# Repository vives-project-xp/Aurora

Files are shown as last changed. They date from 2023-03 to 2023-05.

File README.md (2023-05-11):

# Aurora

Our inspiration for this project is the northern lights in Norway. This is what we want to recreate using ledstrips <br />
We Also will try to develop a person detection system with sensors

Aurora

## Table of contents

- [Short discription](#short-discription)
- [Required](#required)
  - [Hardware](#hardware)
  - [Software](#software)
- [Installation](#installation)
- [Configuration](#configuration)
- [Troubleshooting](#troubleshooting)
- [FAQ](#faq)
- [Maintainers](#maintainers)
- [project photos](#mood-images)

## Short Discription

The project for the ARGB led strip and motion sensors. </br>
This is an interactive LED strip that tracks people and also can display random effects

## Required

These are the required software and hardware

### Software

- Wled
- Arduino
- HTML
- Python
- Javascript
- Docker

### Hardware

- ESP32
- TM1814 led strip
- kabel goot
- 2,5 carre kabels
- breadboard
- Voeding
- ultrasone sensor
- 3d printed brackets
- 3d printed joints

> You can find extra information to buy the right components [here](./HARDWARE.md).

## Installation

> You can find all the information to install this project [here](./INSTALLATION.md).

## Configuration

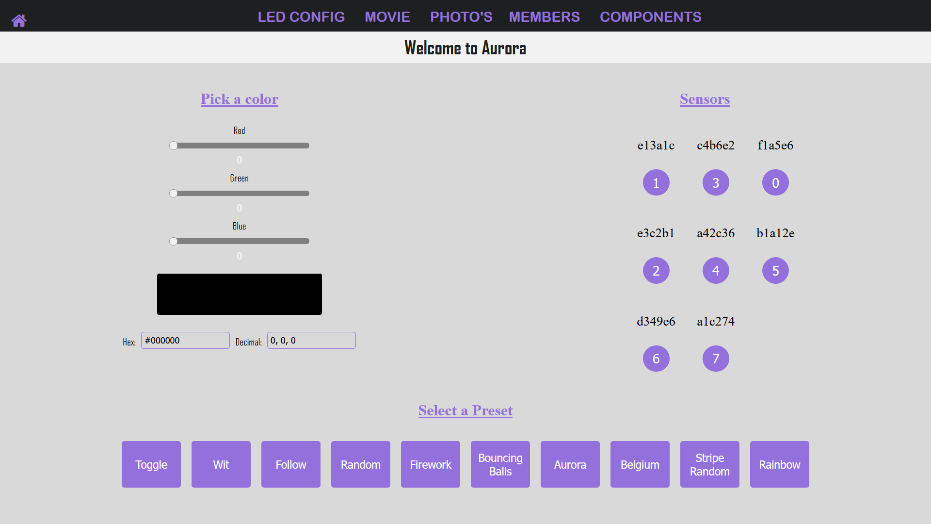
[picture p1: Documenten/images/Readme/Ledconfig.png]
LedConfig


- You can change the color of the ledstrip by dragging the sliders to the correct color.
- To change the order of the sensors, simply change the number under the sensor.
- You can select a preset by clicking on the desired button.

## Troubleshooting

Problems

1. Sensors cannot measure accurately at greater distances
2. Voltage drop on led strip
3. Communication between sensors
4. How to hold up led strip

## FAQ

- How can you add new sensors?
  > Just upload the program on your esp and connect to a WiFi network.
  > The ESP will automatically connect to the server.
-

## Maintainers

Made by Aitor Vannevel, Thibaut Schroyens, Thomas Oddery and Robbe Verhelst

## project Idea

A bridge over the minnewater in 2019 </br>
</br>
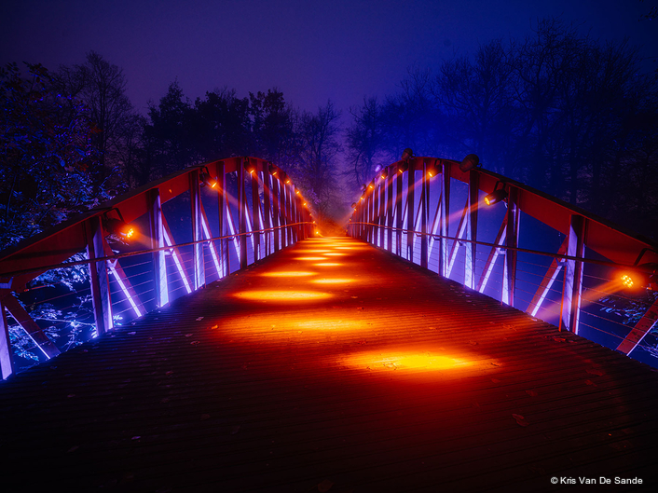
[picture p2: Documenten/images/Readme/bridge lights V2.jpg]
a bridge over the minnewater in 2019


## mood images

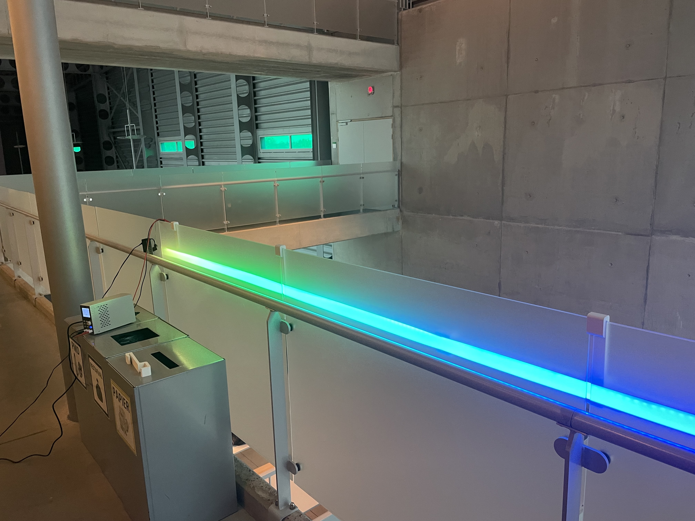
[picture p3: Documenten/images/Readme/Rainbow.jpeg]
Rainbow

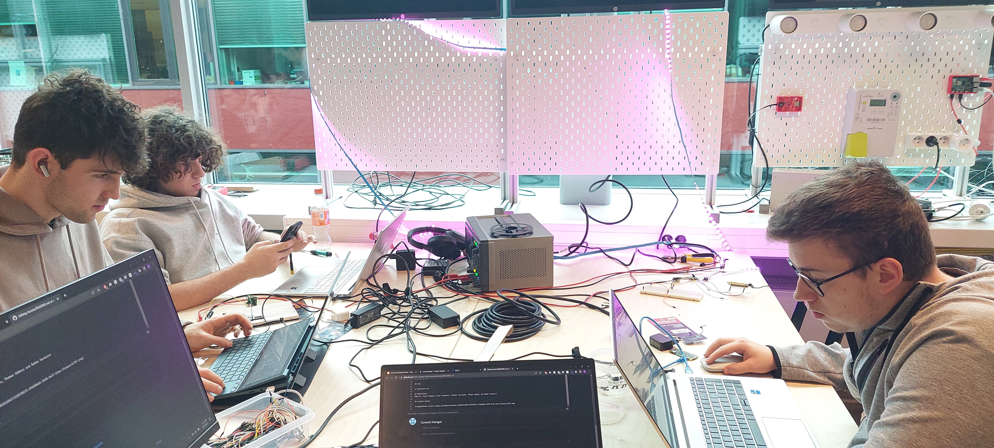
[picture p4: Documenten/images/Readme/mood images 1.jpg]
mood image 1

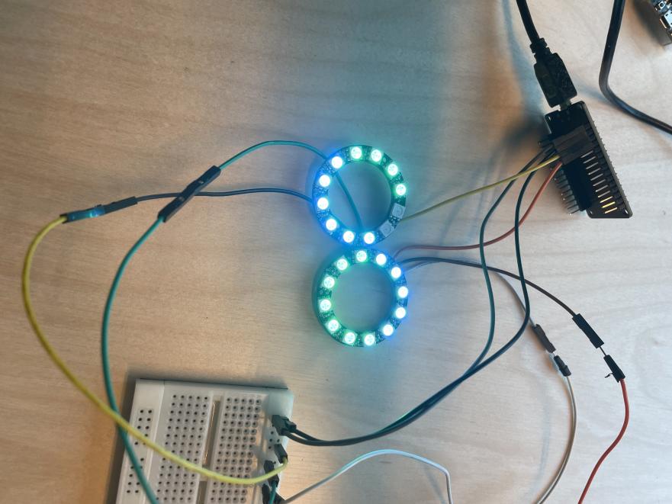
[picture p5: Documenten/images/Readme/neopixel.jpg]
mood image 1
</br>
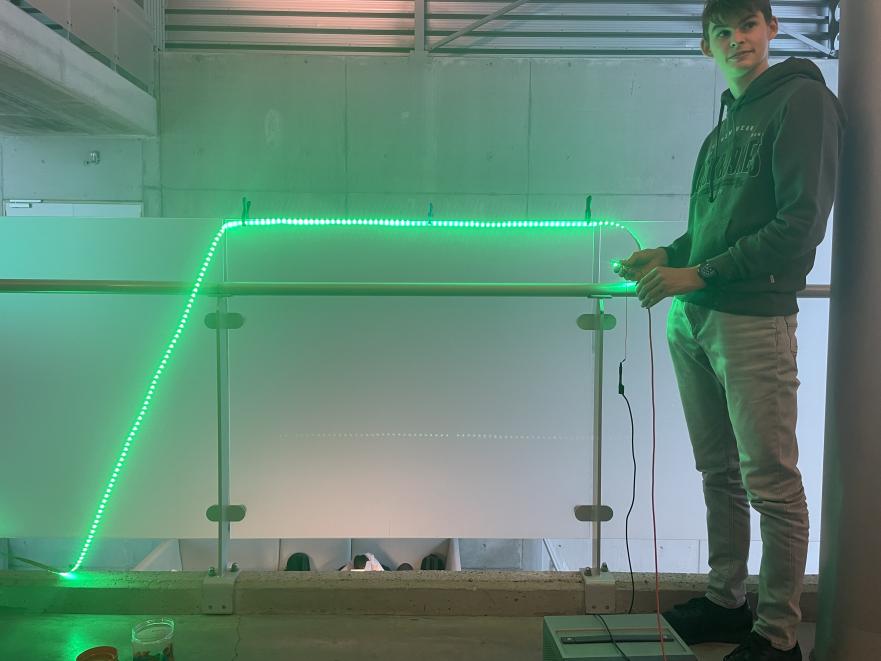
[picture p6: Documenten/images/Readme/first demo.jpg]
mood image 1

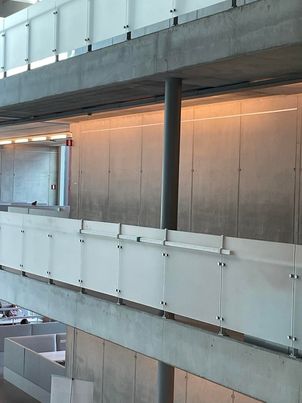
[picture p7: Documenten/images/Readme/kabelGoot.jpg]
mood image 1


## Link to video and powerpoint

Download our powerpoint and video [here](https://vivesonline-my.sharepoint.com/:f:/g/personal/r0937303_student_vives_be/EpYM_1HZu6NDgFsA1ULMHWIBClzqt1kq5hDknEuB2TmHIw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)

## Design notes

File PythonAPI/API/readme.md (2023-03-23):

# API

> **All data should be send in a json format**

You can change the ledstrip by sending http request to **http://aurora.local:5500/**

## Toggle ledstrip
> http request: /toggle

## Set color
> http request: /color

```
{"red": [0-255] ,"green": [0-255] ,"blue": [0-255], "alpha": [0-255]}
```

## Select preset
> http request: /preset

```
{"ps": [0-10]}
```

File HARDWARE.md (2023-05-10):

# Hardware

## Table of contents

- Ledstrip
- Sensor
- ESP32
- Kabelgoot
- 3D prints
- Voeding

## Ledstrip

TM1814 4IN1 5050 RGBW LED Strip Lights Multi Color Chasing, 60LEDs/m

## Sensor

Ultrasonic Distance Sensor HC-SR04 5V!

## ESP32

ESP32 Devkit V1 Board met WiFi Bluetooth en Dual Core processor

## Kabelgoot

Een plastieken kabelgoot van 2,3 cm hoog en 4,3 cm breed.

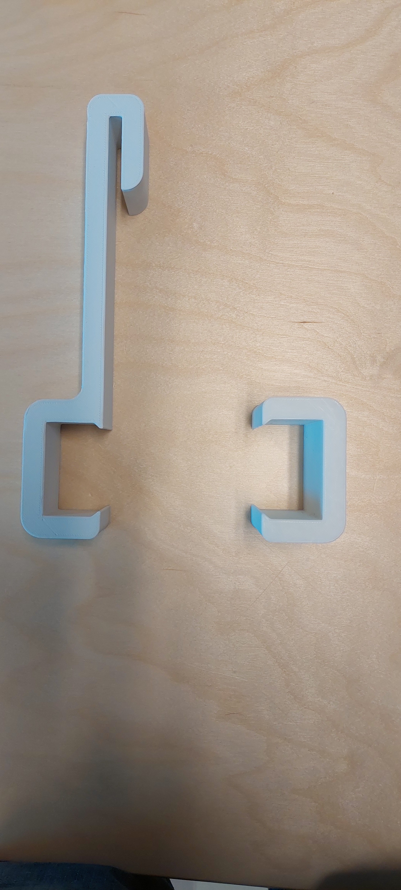
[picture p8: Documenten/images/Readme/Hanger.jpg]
KabelGoot


## 3D prints

3D prints voor de kapelgoot omhoog te houden en cases voor de sensors.

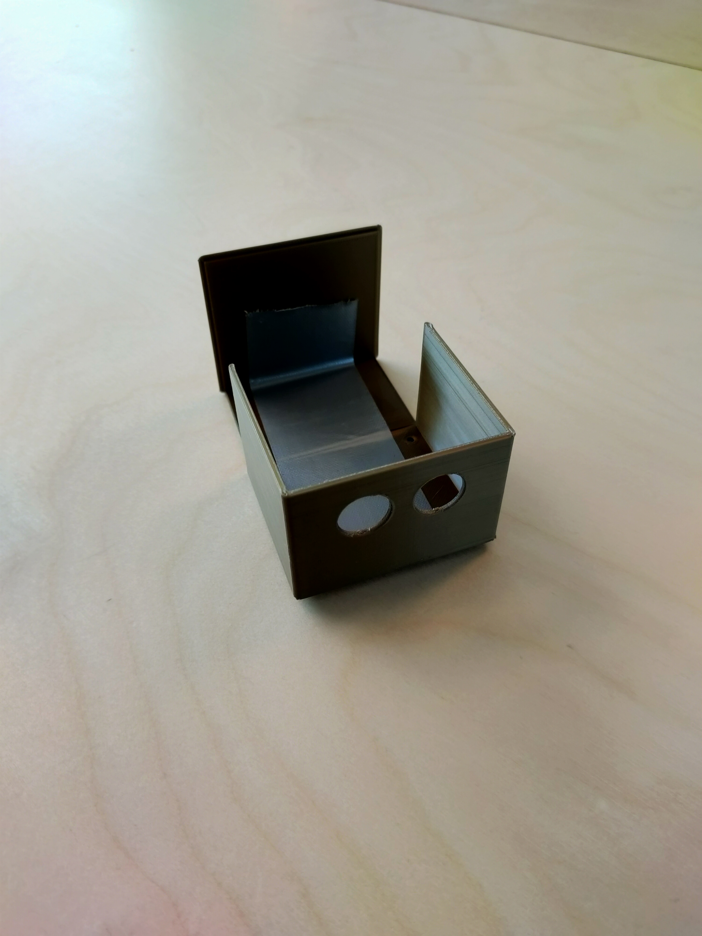
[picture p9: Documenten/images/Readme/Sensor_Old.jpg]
Sensor Old

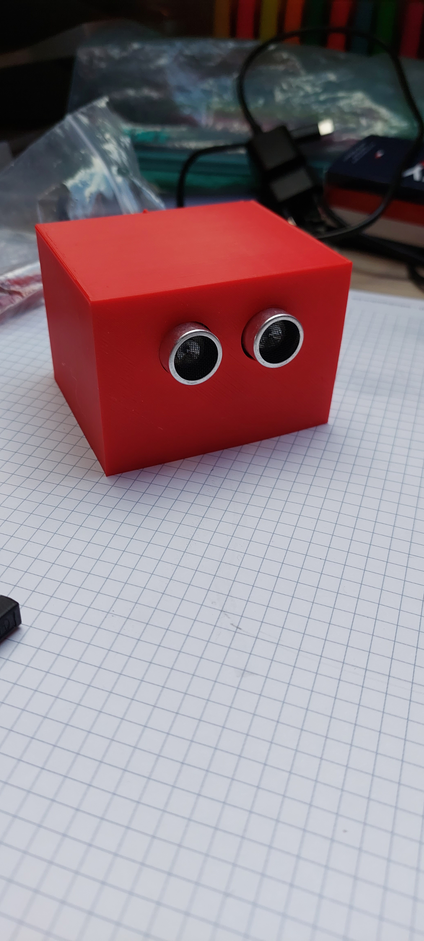
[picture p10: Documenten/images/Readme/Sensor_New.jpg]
Sensor New

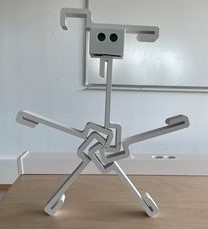
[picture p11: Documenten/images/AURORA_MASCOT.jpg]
AURORA_MASCOT


## Voeding

Meanwelll voeding 24 Volt

AC-DC Industrial DIN rail power supply; Output 24Vdc at 20A; Metal casing; Ultra slim width 85.5mm

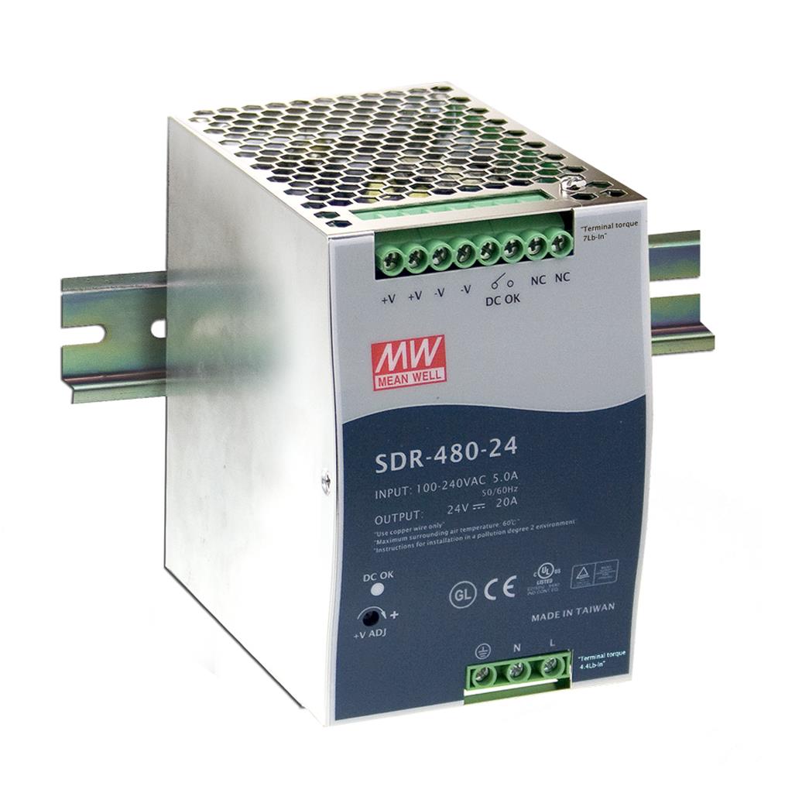
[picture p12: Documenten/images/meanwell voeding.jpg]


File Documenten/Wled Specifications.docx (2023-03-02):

WLed ESP32

- here is a maximum of 10 strips supported
- Contrary to the ESP8266, the pin usage does not matter on ESP32, feel free to use any available pin
- For perfect performance, it is recommeded to use 512 LEDs/pin with 4 outputs for a total of 2048 LEDs.
- For very good performance, it is recommended to use 800 LEDs/pin with 4 outputs for a total of 3200 LEDs.
- For good performance, you can use 1000 LEDs/pin with 4 outputs for a total of 4000 LEDs.
- For okay performance, you can use 1000 LEDs/pin with 5 outputs for a total of 5000 LEDs.
- For okay performance, you can use 800 LEDs/pin with 6 outputs for a total of 4800 LEDs.
- ESP32 can calculate about 65k-85k LEDs per second (that means 1000 LEDs @~70fps, 2000 LEDs @~35fps, 4000 LEDs @~18fps)
- 4 outputs seem to be the sweet spot.

Wled Color leds

70 Voorgeprogrameerde led ideetjes

10 zelf programeerbare led ideetjes

Handige YT links

https://www.youtube.com/watch?v=KFtjf5mD6tA&ab_channel=ChrisMaher

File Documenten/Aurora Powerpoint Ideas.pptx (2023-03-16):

## Project Aurora

By Aitor Vannevel, Thibaut Schroyens, Thomas Oddery, Robbe Verhelst, Glenn Coopman

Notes: Glenn

## Opdracht

Interactive corridor lighting
Build a motion triggered RGB lighting system for the A or B corridor on the third floor.
Challenges
- Creativity is necessary
- Learning to properly create 3D models and prints
- Developing PCB’s

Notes: Thomas

## Problemen

- Voeding problemen
  - niet genoeg ampère
  - Grote voeding niet in gang
  - Ledstrip niet fel genoeg
- Bestelling vertraagd
- Python problemen
- Nieuwe programmeertalen leren kennen
- Pir sensor werkt niet

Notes: Thibaut

## Volgende Stappen

Week 5

- Troubleshooting
- klein prototype bouwen
- kijken voeding alternatief
- 3d print massaal maken

Week 6

- Groot prototype bouwen
- Grote voedingen testen
- concept of how it works uitschrijven

Week 7

- Alle communicatie op punt stellen.
- kinderziektes er uit halen

Week 8

Installeren van een final product op de juiste locatie

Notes: Robbe

## Schema’s

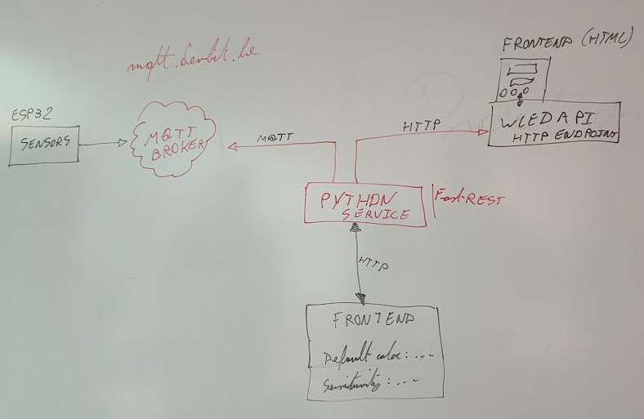
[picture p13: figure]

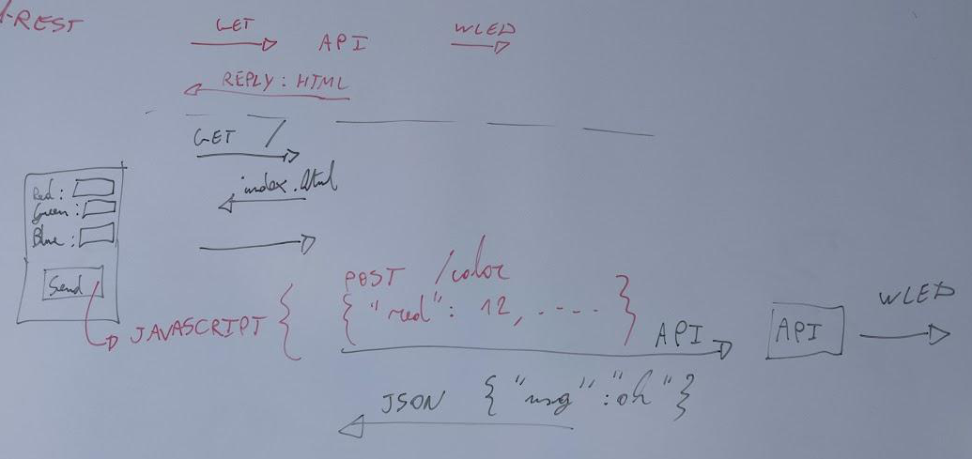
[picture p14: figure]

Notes: Aitor

## Korte Demo

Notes: Een beetje iedereen

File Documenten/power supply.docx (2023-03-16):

https://relicelectrical.ca/products/dc-24v-480w-ip20-universal-regulated-switching-led-transformer

Schatting:

24V - 3A

60m = 24V - 36A

voeding aan elke kant parallel geschakeld 24V - 18A

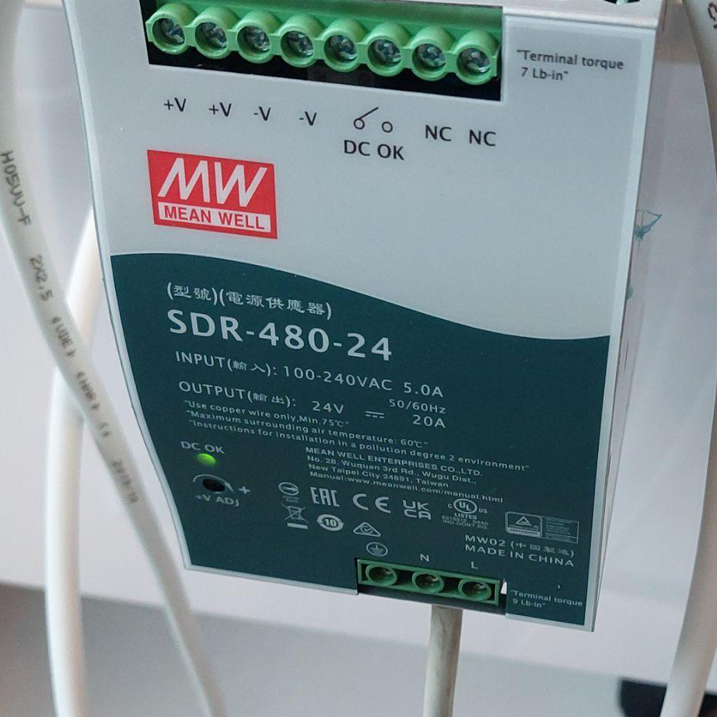
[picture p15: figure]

2X SDR 480-24

https://www.meanwell-web.com/en-gb/ac-dc-industrial-din-rail-power-supply-output-sdr--480--24

Output Power (W) → 480

Output Voltage (V) → 24

Output Current (A) → 20

https://www.meanwell-web.com/en-gb/shop/basket dubbel fack

aansluiting Naar Net

Ground

2 Powers

output V+ en V-

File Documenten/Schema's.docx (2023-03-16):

ESP32 + 1 Led strip

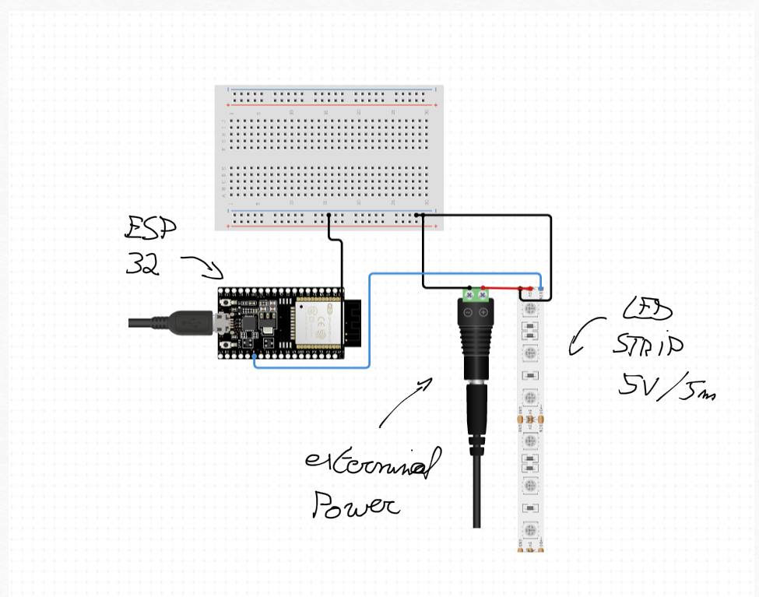
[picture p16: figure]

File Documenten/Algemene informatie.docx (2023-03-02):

_-_-_-_-_-_-_-_-_-_-_-_-_-_-_-_-TEKENINGEN_-_-_-_-_-_-_-_-_-_-_-_-_-_-_-_-_-_-_-_-_-_-_-_

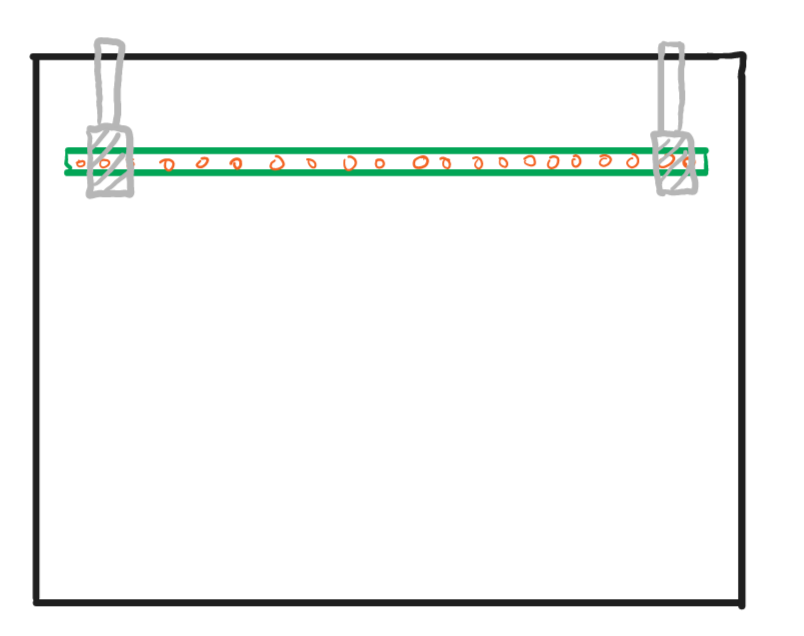
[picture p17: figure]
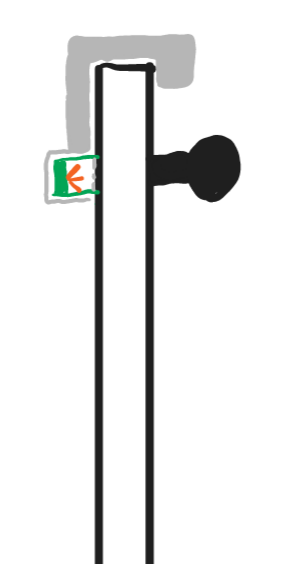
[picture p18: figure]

_-_-_-_-_-_-_-_-_-_-_-_-_-_-_-_-_- INFO_-_-_-_-_-_-_-_-_-_-_-_-_-_-_-_-_-_-_-_-_-_-_-_

32 meters of length

28 poles (A-B) → 9 voor 10 meter test

-https://quinled.info/addressable-digital-leds/#DigitalBuy

_-_-_-_-_-_-_-_-_-_-_-_-_-_-_-_-_- DEEP thoughts -_-_-_-_-_-_-_-_-_-_-_-_-_-_-_-_-_

- Already trailing light
- Lighting up the panell where a sensor (person present) is activated
- More than 8 sensors sensing the whole line firework
- When there are two people going to each other when they meet a big explosion
- BOEMMMM zone grote vuurbal (school weg) haha grapje met de leds he ;)...Of toch niet
- adding sound? (depended on the speed?????????????)

_-_-_-_-_-_-_-_-_-_-_-_-_-_-_-_-_- TROUBLES -_-_-_-_-_-_-_-_-_-_-_-_-_-_-_-_-_

- Power? Hoe verdelen? Genoeg amp voorzien?

_-_-_-_-_-_-_-_-_-_-_-_-_-_-_-screen saver animations -_-_-_-_-_-_-_-_-_-_-_-_-_-_-_-_-_

- Snake
- Snowflake (in colors)
- Fireworks
- Random pulsen op de lijn (t-bo achtergrond)
- Hart rate in stukken van de lijn.

Apparaat | Price | Beschrijving | Link

ARGB 5m 5050

WS2811ALL

2 * € 17,65 per 5m

Geeft licht

https://www.amazon.de/WS28115M60LB30-WS2811ALL/dp/B01CNL6K52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
‘goot’ | 3,79 per 250cm 10 meter → 4x | -goedkoper dan plastiek -zal niet buigen zoals plastiek (straight line) | https://www.gamma.be/nl/assortiment/hoekprofiel-gegalvaniseerd-2-5m/p/B882154
cPIR Sensor | 10 * 2,49 | – Detectie afstand: 3-7m. – Vertraging: 5-200s – Output voltage: 3.3V - Werkt op: 4.5-20V – Detectiehoek: <140°. Kunnen dit verminderen met De gedrieprinte behuizing | https://www.otronic.nl/nl/pir-sensor-hc-sr501-bewegingssensor.html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
Infrared Emitter | 10 * 0,162 € | Infrarood emmiter | https://be.farnell.com/multicomp/ofl-5102/infrared-emitter-940nm-t-1-3-4/dp/1716710
Phototransistor | 10 * 0,94 € | Phototransitor | https://be.farnell.com/vishay/bpv11f/phototransistor-t1-3-4/dp/1045379?ost=1045379
ESP | 2 * 9,89 € | Compatible with Wled | https://www.otronic.nl/nl/esp32-wroom-4mb-devkit-v1-board-met-wifi-bluetooth.html

Planning

| BESCHRIJVING | Occupants
Week 1 | Infrabel aszsholes, was wel goeie burgur tho. thompie op insta gekomen | all
Week 2 | Alle onderdelen bestellen, weten hoe we het probleem zullen oplossen | all
Week 3 | software/hardware symbiose + concept of working prototype
Week 4 | Een kleine prototype bouwen (1-2 sensors, paar leds) + 3d prints design | 3d (Thomas)
Week 5 | Trouble shooting klein prototype bouwen + kijken voeding alternatief + 3d maken
Week 6 | Groot prototype bouwen + voedingsproblemen oplossen + 3d printen + concept of how it works
Week 7 | 3d prints moeten af zijn.
Week 8 | Installeren van alles op juiste locaties
Week 9 | Werking project volledig + bakje animaties installeren
Week 10 | Powerpoint moet af zijn + animations maken + vollediging af
Week 11 | Filmpje moet af zijn. + animations maken
Week 12 | Final checks

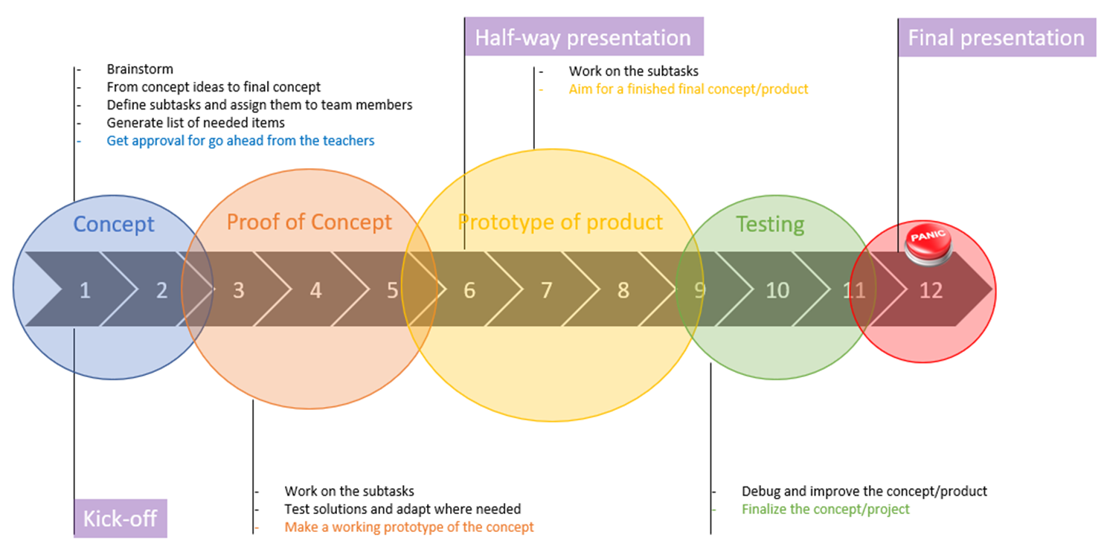
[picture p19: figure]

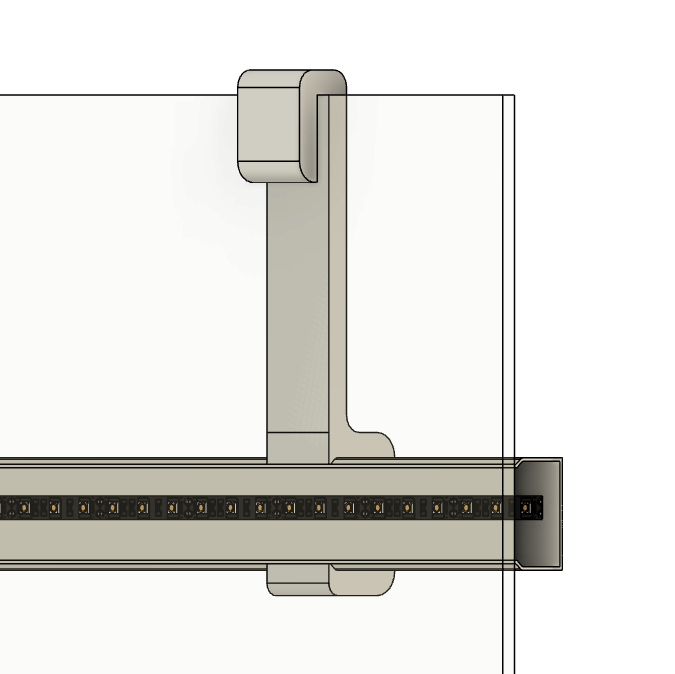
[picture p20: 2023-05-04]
Video/images/Schermafbeelding 2023-05-04 153837.png

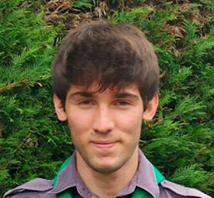
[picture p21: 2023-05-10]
website/html/images/Thibaut photo.png

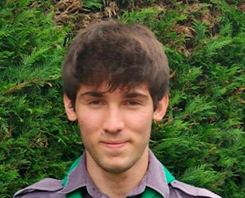
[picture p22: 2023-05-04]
Video/images/Afbeelding2.png

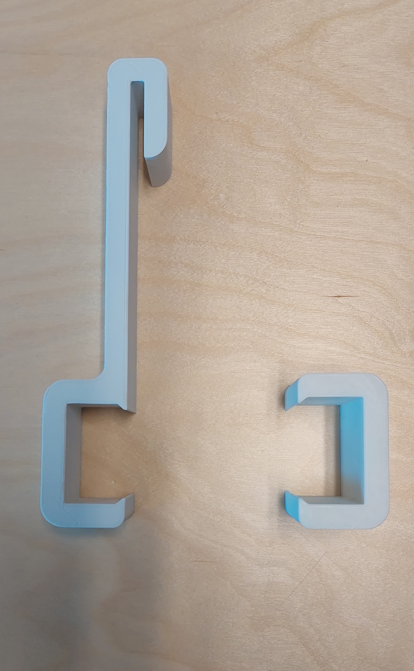
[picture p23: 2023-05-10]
website/html/images/3dprints.jpg

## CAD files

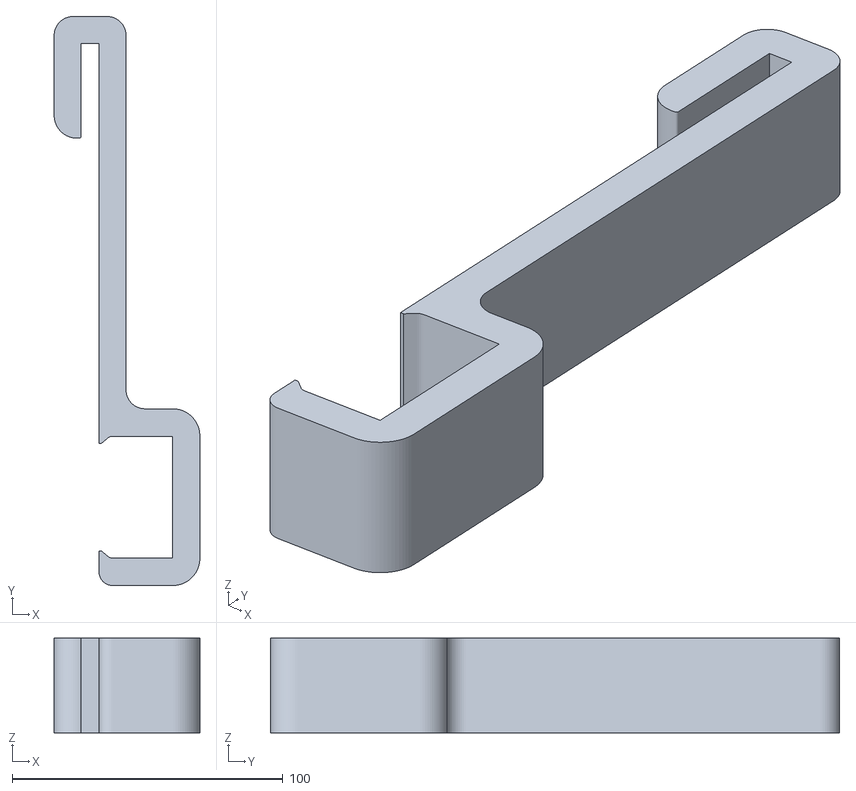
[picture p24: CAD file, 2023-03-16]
3D_Drawings/STL-files/firstFullPrototype.stl
53.9 x 210.3 x 35.0

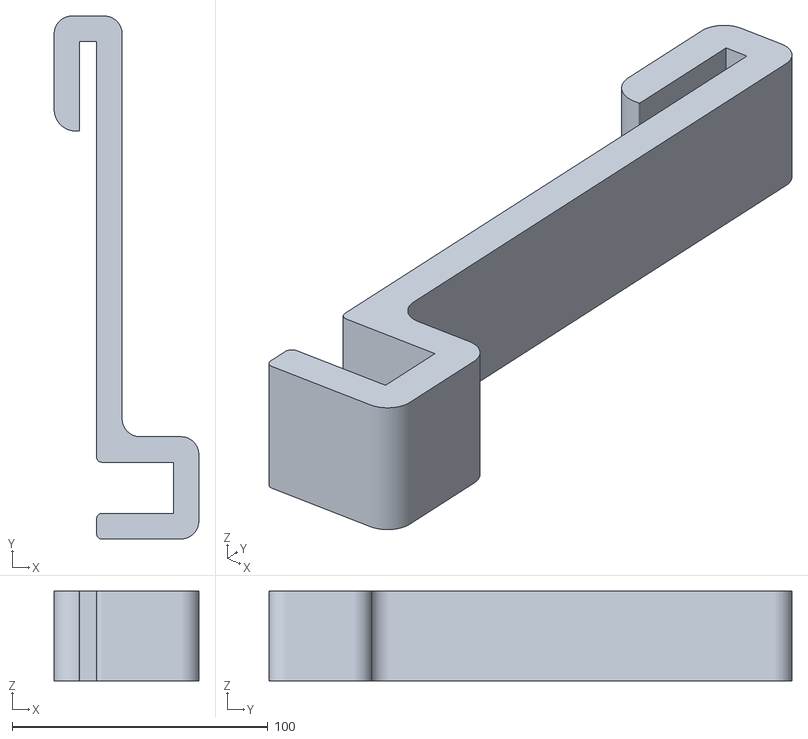
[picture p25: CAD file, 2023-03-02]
3D_Drawings/STL-files/FullHolder_v01.stl
56.6 x 204.5 x 35.0

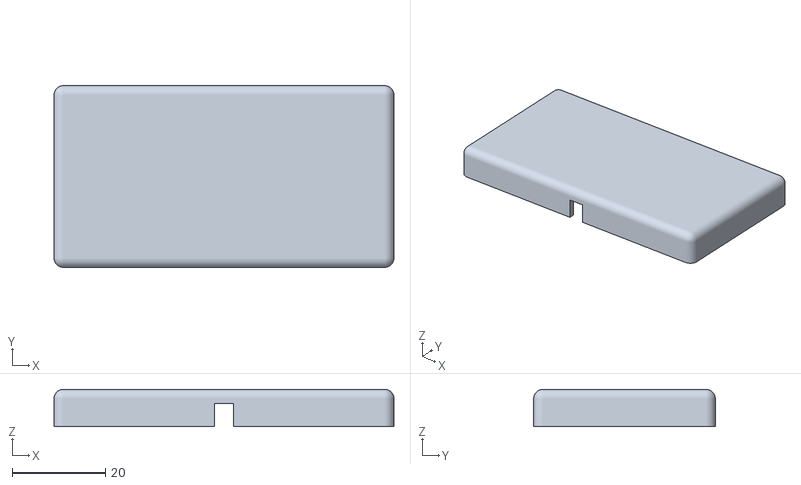
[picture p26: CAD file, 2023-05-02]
3D_Drawings/STL-files/SensorBoxDeksel_v02.stl
73.0 x 39.0 x 8.00

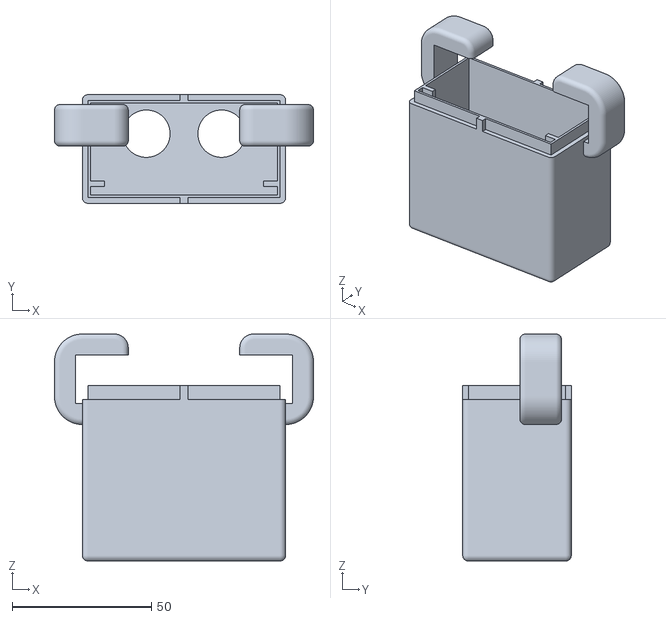
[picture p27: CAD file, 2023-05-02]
3D_Drawings/STL-files/SensorBoxCase_v02.stl
93.0 x 39.0 x 81.5

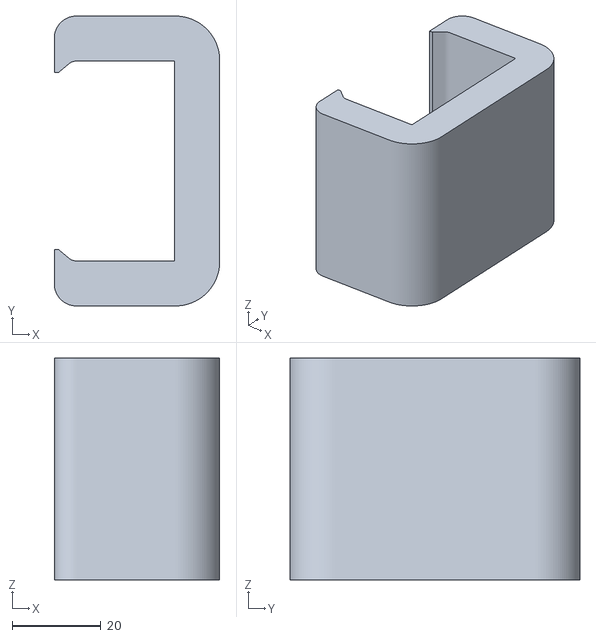
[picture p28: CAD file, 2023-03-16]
3D_Drawings/STL-files/TussenStukHolder2_v00.stl
37.3 x 65.3 x 50.0

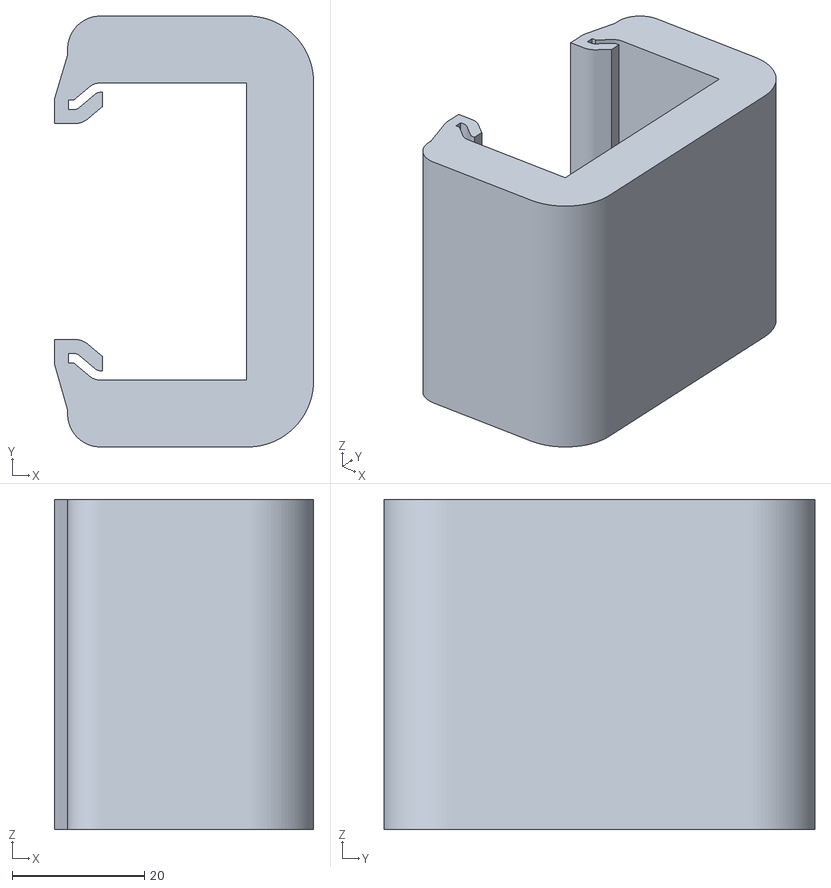
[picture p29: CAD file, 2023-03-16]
3D_Drawings/STL-files/TussenStukHolder_v00.stl
39.3 x 65.3 x 50.0

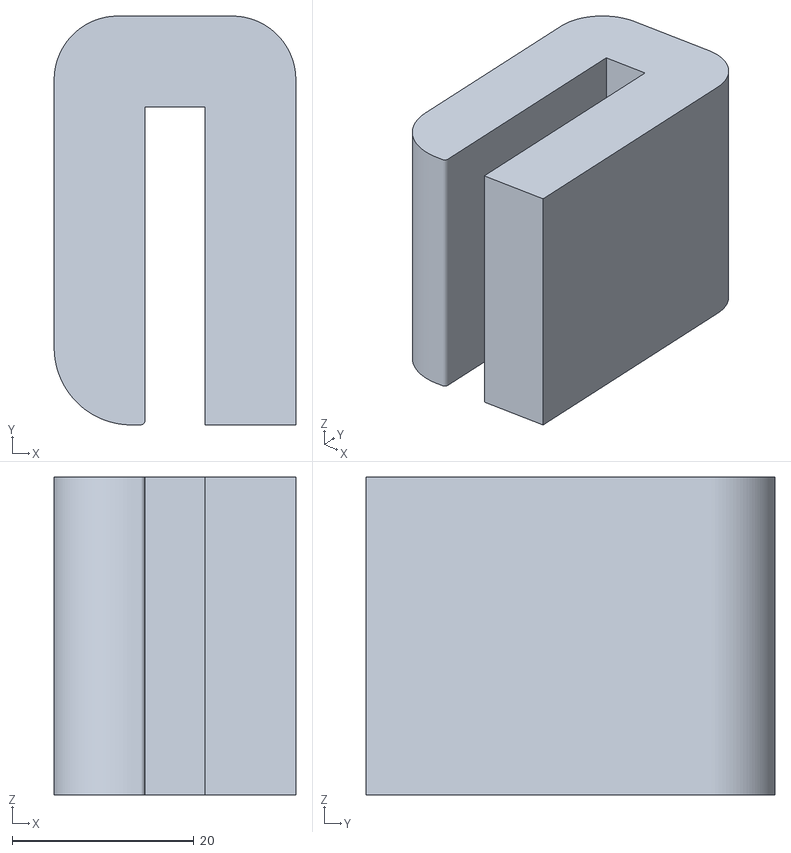
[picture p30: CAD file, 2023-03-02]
3D_Drawings/STL-files/HolderTopPart_v00.stl
26.6 x 45.0 x 35.0

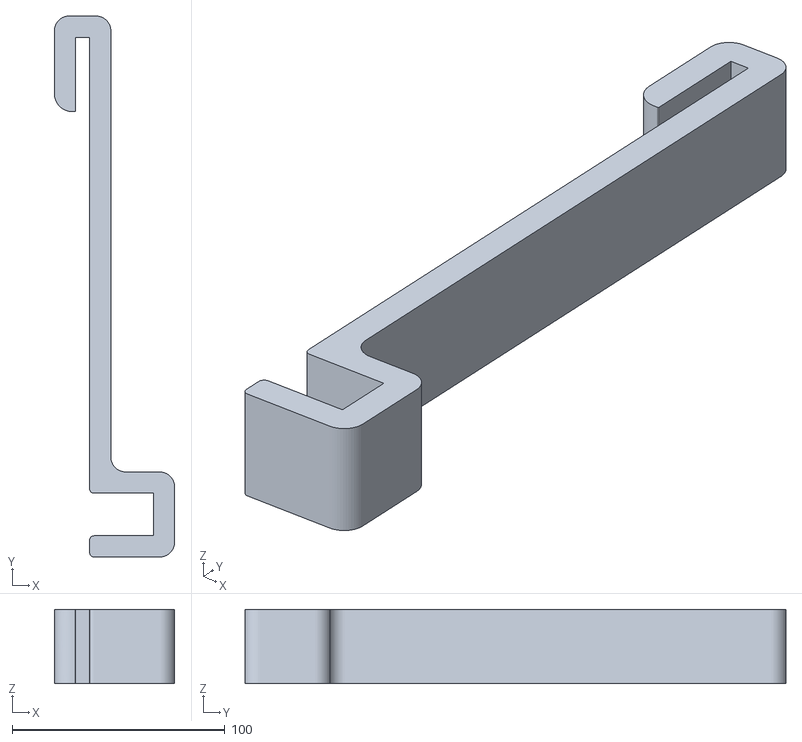
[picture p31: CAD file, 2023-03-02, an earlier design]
3D_Drawings/STL-files/FullHolder_v00.stl
56.6 x 254.5 x 35.0

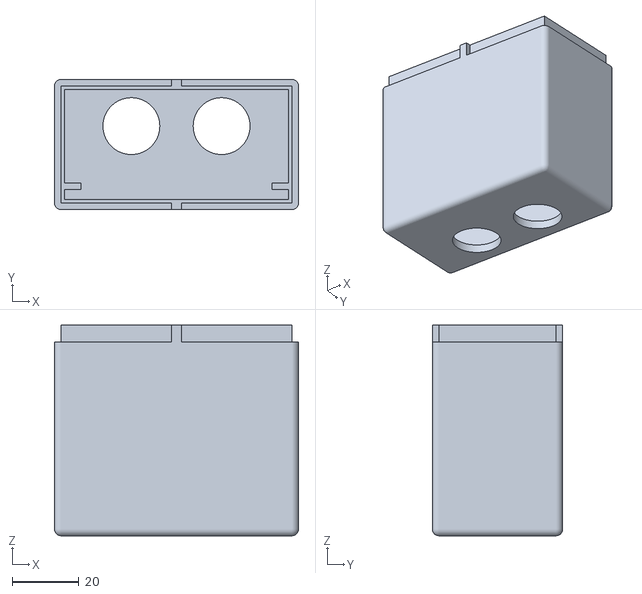
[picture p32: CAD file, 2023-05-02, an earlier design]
3D_Drawings/STL-files/SensorBoxCase_v01.stl
73.0 x 39.0 x 63.0

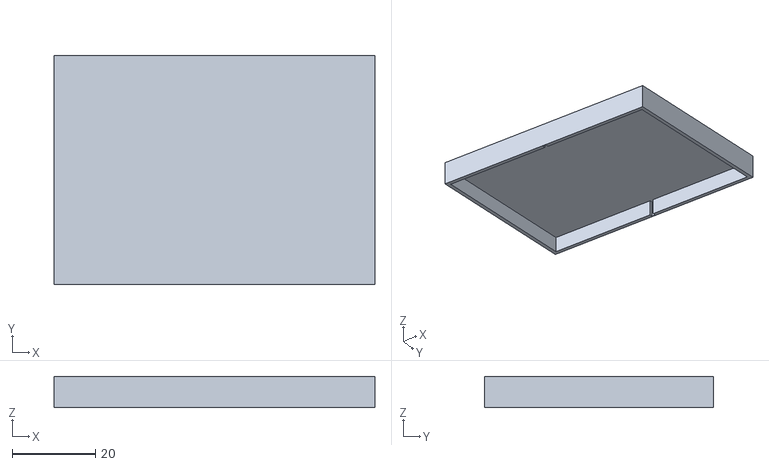
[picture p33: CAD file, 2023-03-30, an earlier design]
3D_Drawings/STL-files/SensorBoxDeksel_v00.stl
77.0 x 55.0 x 7.50

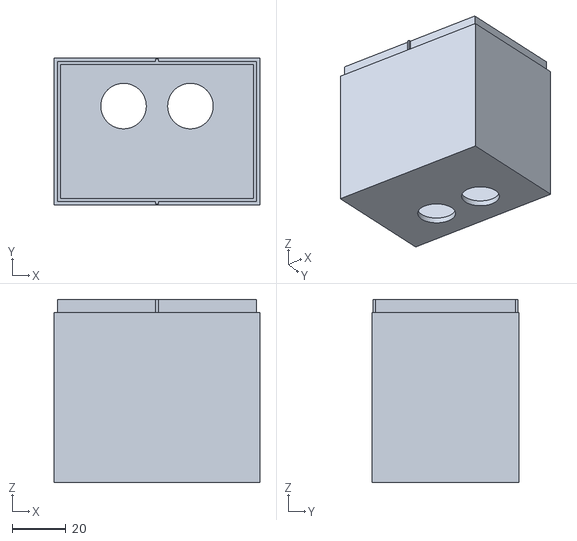
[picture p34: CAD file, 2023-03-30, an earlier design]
3D_Drawings/STL-files/SensorBoxCase_v00.stl
77.0 x 55.0 x 68.5

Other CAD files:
3D_Drawings/STL-files/SensorBoxDeksel_v01.stl
3D_Drawings/holder v1.f3d

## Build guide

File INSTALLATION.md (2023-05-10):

Use the [Raspberry Pi Imager](https://www.raspberrypi.com/software/) to install Raspberry pi os on a raspberry pi

Select Raspberry PI OS

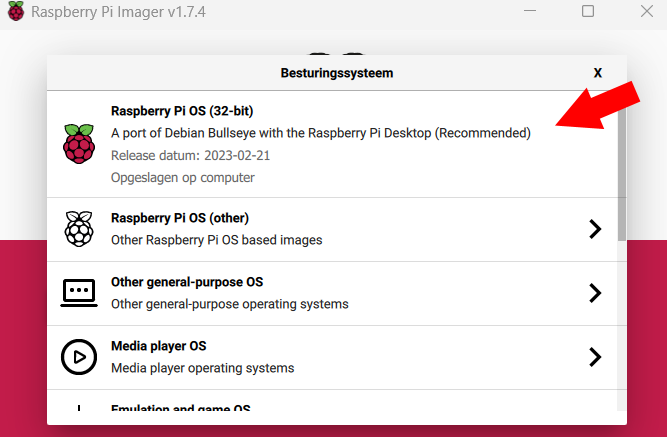
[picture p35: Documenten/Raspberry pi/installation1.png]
RaspberryPiOs


Choose your destination location.
Select the gear icon in the right bottom corner.
Change hostname to **aurora**.local

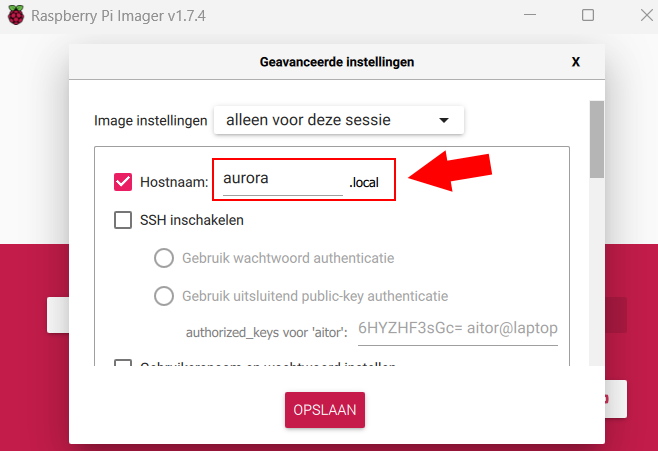
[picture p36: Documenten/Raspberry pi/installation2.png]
aurora.local


Choose your **username** and **password**.

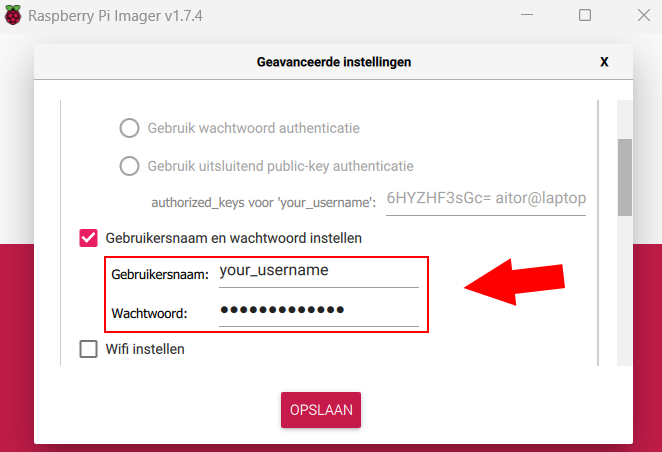
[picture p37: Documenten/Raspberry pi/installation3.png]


Setup your wifi credentials.

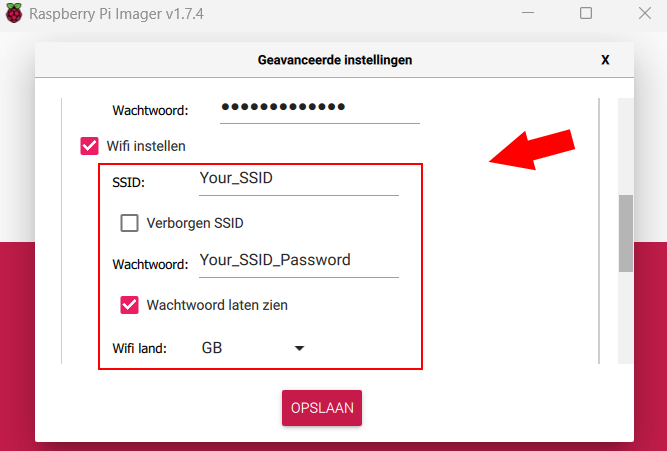
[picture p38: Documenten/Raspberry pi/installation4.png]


Save your settings and start the installation.
Once the installation is finished.
Insert the sd-card into the Pi and boot it up.

Once booted up. Login using [SSH](https://tutorials-raspberrypi.com/raspberry-pi-remote-access-by-using-ssh-and-putty/). The hostname should be **aurora.local** and use your username and password.

Run the following commands:

```
sudo apt-get update
sudo apt-get upgrade
sudo reboot
```

### Install git:

```
sudo apt install git
git config --global user.name "Your Name"
git config --global user.email "youremail@yourdomain.com"
```

Once you have git installed, you can clone our project to the Raspberry Pi.

```
git clone https://github.com/vives-project-xp/Aurora.git
```

### Install Docker:

Give the user permission to use docker.

```
sudo groupadd docker
sudo usermod -aG docker $USER
sudo reboot
```

Install Docker

```
curl -sSL https://get.docker.com | sh
```

Once docker is installed, you can start our project.

```
docker compose up -d --build
```

It can take a while until everything has downloaden
If everything works as it should, you can search for [aurora.local](http://aurora.local/)

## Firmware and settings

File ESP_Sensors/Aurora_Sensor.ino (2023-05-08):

#include <WiFi.h>
#include "PubSubClient.h" 
#include "Freenove_WS2812_Lib_for_ESP32.h"
#include <ArduinoJson.h>
#include "hc_sr04.h"
#include "config.h"


using namespace Sonic;

#define FIRMWARE_VERSION "v0.1"

// HS SR04 Ultrasonic Sensor Pins
#define TRIGGER_PIN 0
#define ECHO_PIN    1

Sensors::HC_SR04 ultrasonicSensor(TRIGGER_PIN, ECHO_PIN);

// Communications
WiFiClient wifiClient;
PubSubClient mqttClient(wifiClient); 
String mqttClientId = "";

// RGB LED
#define RGB_COUNT     1
#define RGB_PIN       8
#define RGB_CHANNEL   0
String prefix = "Aurora_sensor";
bool isConnected = false;

Freenove_ESP32_WS2812 strip = Freenove_ESP32_WS2812(RGB_COUNT, RGB_PIN, RGB_CHANNEL, TYPE_GRB);

void status_no_communications(void) {
  strip.setLedColorData(0,255,0,0);
  strip.show();
}

void status_wifi_ok(void) {
  strip.setLedColorData(0, 255, 127, 0);
  strip.show();
}

void status_communications_ok(void) {
  strip.setLedColorData(0, 0, 255, 0);
  strip.show();
}

bool connect_to_wifi(void) {
  Serial.print("Connecting to WiFi ");
  Serial.println(Config::WIFI_SSID);

  WiFi.begin(Config::WIFI_SSID, Config::WIFI_PASSWORD);

  while (WiFi.status() != WL_CONNECTED) {
    delay(1000);
    Serial.println("Not yet connected ...");
  }

  Serial.println("Connected to WiFi");
  return true;
}

String get_client_id(void) {
  // static long randomId = random(1000,9999);
  String mqttClientId = WiFi.macAddress().substring(9);
  mqttClientId.replace(":", "");
  mqttClientId.toLowerCase();
  mqttClientId = prefix + mqttClientId;    // + String(randomId);
  return mqttClientId;
}

bool connect_to_mqtt_broker(void) {
  mqttClient.setServer(Config::MQTT_BROKER_IP, Config::MQTT_BROKER_PORT);

  if (mqttClient.connect(get_client_id().c_str())) {
    Serial.print("Connected to MQTT Broker as ");
    Serial.println(get_client_id());
  }
  else {
    Serial.println("Connection to MQTT Broker failed ..");
  }

  return mqttClient.connected();
}

void publish_ultrasonic_distance(int distance) {
  String commandTopic = Config::MQTT_BASE_TOPIC;

  char output[128];
  StaticJsonDocument<128> message;

  message["id"] = get_client_id();
  message["distance"] = distance;

  serializeJson(message, output);

  Serial.print("Publishing measurement message ");
  Serial.println(distance);
  String topic = commandTopic + '/' + get_client_id().substring(prefix.length()) + "/dist";
  mqttClient.publish(topic.c_str(), output);
}

void mqtt_subscribe_callback(char *topic, byte *payload, unsigned int length) {
  char message[64];
  if (length >= sizeof(message)) {
    Serial.println("Received MQTT message but it was too large.");
    return;
  }

  memcpy(message, payload, length);
  message[length] = '\0';
  
  Serial.print("Following message arrived @ ");
  Serial.println(topic);
  Serial.println(message);
  Serial.println("---------------------------");

  StaticJsonDocument<128> doc;        // Not sure how much bigger it needs to be than buffer
  deserializeJson(doc, message);

  const char* command = doc["cmd"];
  const char* sensor = doc["sensor"];
  const int count = 1;
  if(String(sensor) == get_client_id().substring(prefix.length())){
    isConnected = true;
    if (!strcmp(doc["cmd"], "measure")) {
      byte distance[count];
      for(byte i = 0; i <count ;i++){
       //distance[i] = ultrasonicSensor.measure_distance_cm();
       distance[i] = measure_distance_cm_new();
        //delayMicroseconds(30);
      }
      
      int dist = distance[0];
      for(int i = 0; i < count;i++){
        if(distance[i] > dist){
          dist = distance[i];
        }
      }
       publish_ultrasonic_distance(dist);
    }
  }
}

int measure_distance_cm_new(){
    digitalWrite(TRIGGER_PIN, LOW);
  delayMicroseconds(2);
  // Sets the trigPin on HIGH state for 10 micro seconds
  digitalWrite(TRIGGER_PIN, HIGH);
  delayMicroseconds(10);
  digitalWrite(TRIGGER_PIN, LOW);
  // Reads the echoPin, returns the sound wave travel time in microseconds
  long duration = pulseIn(ECHO_PIN, HIGH);
  // Calculating the distance
  int distance = duration * 0.0171;
  // Prints the distance on the Serial Monitor
  return distance;
}

void publish_hello_package(void) {
  String helloTopic = Config::MQTT_BASE_TOPIC + "/connect";

  char output[128];
  StaticJsonDocument<128> message;

  message["id"] = get_client_id();

  serializeJson(message, output);

  Serial.println("Publishing hello message");
  mqttClient.publish(helloTopic.c_str(), output);
}

void setup_mqtt_subscriptions(void) {
  mqttClient.setCallback(mqtt_subscribe_callback);

  String clientId = get_client_id();
  String commandTopic = Config::MQTT_BASE_TOPIC + "/" + clientId.substring(prefix.length()) + "/measure";

  mqttClient.subscribe(commandTopic.c_str());
  mqttClient.subscribe((Config::MQTT_BASE_TOPIC + "/" + clientId.substring(prefix.length())+ "/connected").c_str());
}

void setup() {
  Serial.begin(115200);

  // if analog input pin 0 is unconnected, random analog
  // noise will cause the call to randomSeed() to generate
  // different seed numbers each time the sketch runs.
  // randomSeed() will then shuffle the random function.
  // randomSeed(analogRead(0));

  // Configure RGB Led
  strip.begin();
  strip.setBrightness(10);
  status_no_communications();

  // Configure HS SR04 Ultrasonic Sensor Module pins
  pinMode(TRIGGER_PIN, OUTPUT);
  pinMode(ECHO_PIN, INPUT);

  Serial.println("Starting firmware of ESP32-C3 Sonic Module ...");
  Serial.print("MAC Address: ");
  Serial.println(WiFi.macAddress());
  

  connect_to_wifi();
  connect_to_mqtt_broker();
  setup_mqtt_subscriptions();
}

void loop() {
  // Needs cleanup but for the moment ok
  if (WiFi.status() != WL_CONNECTED) {
    isConnected = false;
    status_no_communications();
    connect_to_wifi();
    delay(1000);
  }
  if (WiFi.status() == WL_CONNECTED && !mqttClient.connected()) {
    isConnected = false;
    status_wifi_ok();
    connect_to_mqtt_broker();
    delay(1000);
  }
  if (WiFi.status() == WL_CONNECTED && mqttClient.connected()) {
    setup_mqtt_subscriptions();
    if(!isConnected){
      publish_hello_package();
      delay(2000);
    }else{
          status_communications_ok();
    }
  }
  // Give client processing time
  mqttClient.loop();
}

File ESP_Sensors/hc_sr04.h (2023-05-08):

namespace Sensors {

  class HC_SR04 {

    public:
      HC_SR04(int triggerPin, int echoPin)
        : _triggerPin(triggerPin), _echoPin(echoPin) {

        pinMode(_triggerPin, OUTPUT);
        pinMode(_echoPin, INPUT);
        digitalWrite(_triggerPin, LOW);
      }

    public:
      int measure_distance_cm(void) {
        digitalWrite(_triggerPin, HIGH);
        delayMicroseconds(10);
        digitalWrite(_triggerPin, LOW);
    
        unsigned long duration_us = pulseIn(_echoPin, HIGH);      // Can take in timeout, should we add one?
        int distance_cm = (0.0172 * duration_us);
        Serial.println(distance_cm);
        if (distance_cm <= 300 && distance_cm > 0) return distance_cm;
        else return -1;
      }

    private:
      int _triggerPin;
      int _echoPin;
  };

};

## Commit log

2023-03-02 3D_Prints/holder v1.f3d
    [holder v1.f3d]
2023-03-02 Added the Holder 3D drawing and the test print STL
    [HolderTopPart_v00.stl, holder v1.f3d]
2023-03-02 FUll holder STL
    [Body1.stl]
2023-03-09 Made de Mqtt esp folder
2023-03-16 Made the full first prototype of the holder
    [firstFullPrototype.stl]
2023-03-16 Documents added 'Powerpoint'
2023-03-16 3D print tussenstuk and wa code van MQTT
    [Body3.stl]
2023-03-16 second tussenstuk
    [TussenStukHolder2_v00.stl]
2023-03-23 Addec controlling ledstrip with sensors
2023-03-30 made the sensor case prototype
    [SensorBoxCase_v00.stl, SensorBoxDeksel_v00.stl]
2023-03-30 Hardware.md meanwell powersupply
2023-04-27 nieuwe case
    [SensorBoxCase_v01.stl, SensorBoxDeksel_v01.stl]
2023-05-04 updated ledconfig
2023-05-04 fixed sensors
